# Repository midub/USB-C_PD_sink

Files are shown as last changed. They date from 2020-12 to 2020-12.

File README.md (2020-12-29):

# USB-C Power Delivery sink
A board that negotiates voltage with PD compatible power supply.

				An easy way to bring USB-C power to your own project.

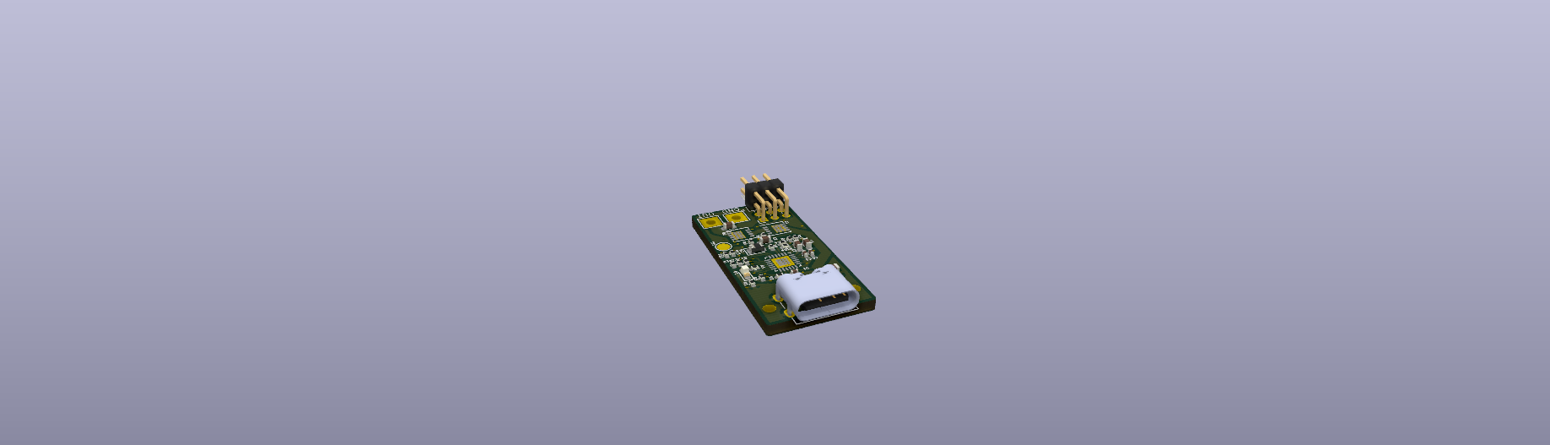
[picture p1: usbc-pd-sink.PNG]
A little board USB-C Power Delivery sink


### Features
- Utilizes Cypress semiconductor's [CYPD3177](https://www.cypress.com/file/460416/download) IC.
- Tiny 32x16 mm board.
- Up to 3A current thanks to quality components.
- Set voltage by specified resistor value or by I2C.
- Access to I2C, GPIO_1, Interupt and Flip pins that are wired out to a 2x3 1.27mm pitch pin header.
- Screw holes next to usb-c port for better attachment.

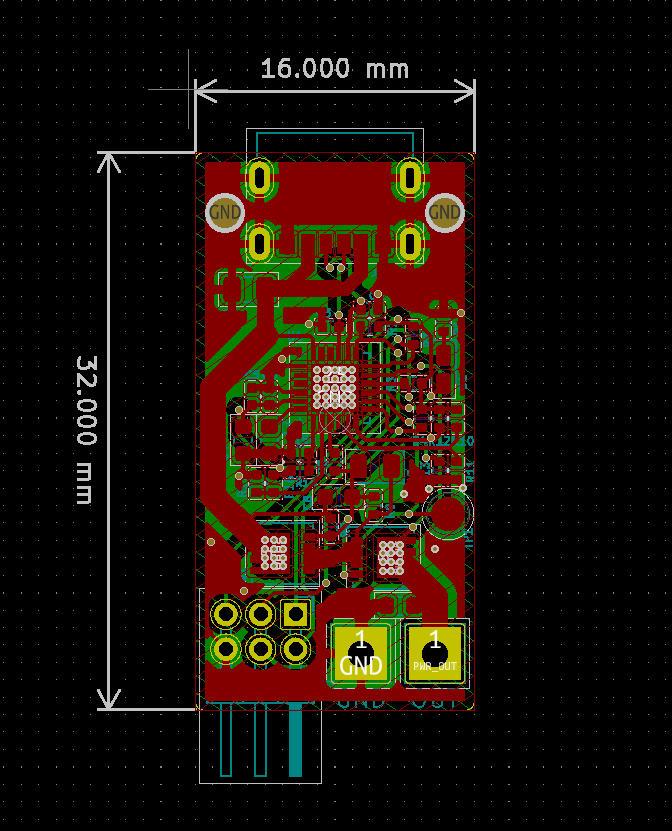
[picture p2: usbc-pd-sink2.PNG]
PCB footprint


### Todos
- Replace output power pins with fastons or othes suitable common connector.
- Create a design block, which can be used by powered board.

## DISCLAIMER: Use at your own risk

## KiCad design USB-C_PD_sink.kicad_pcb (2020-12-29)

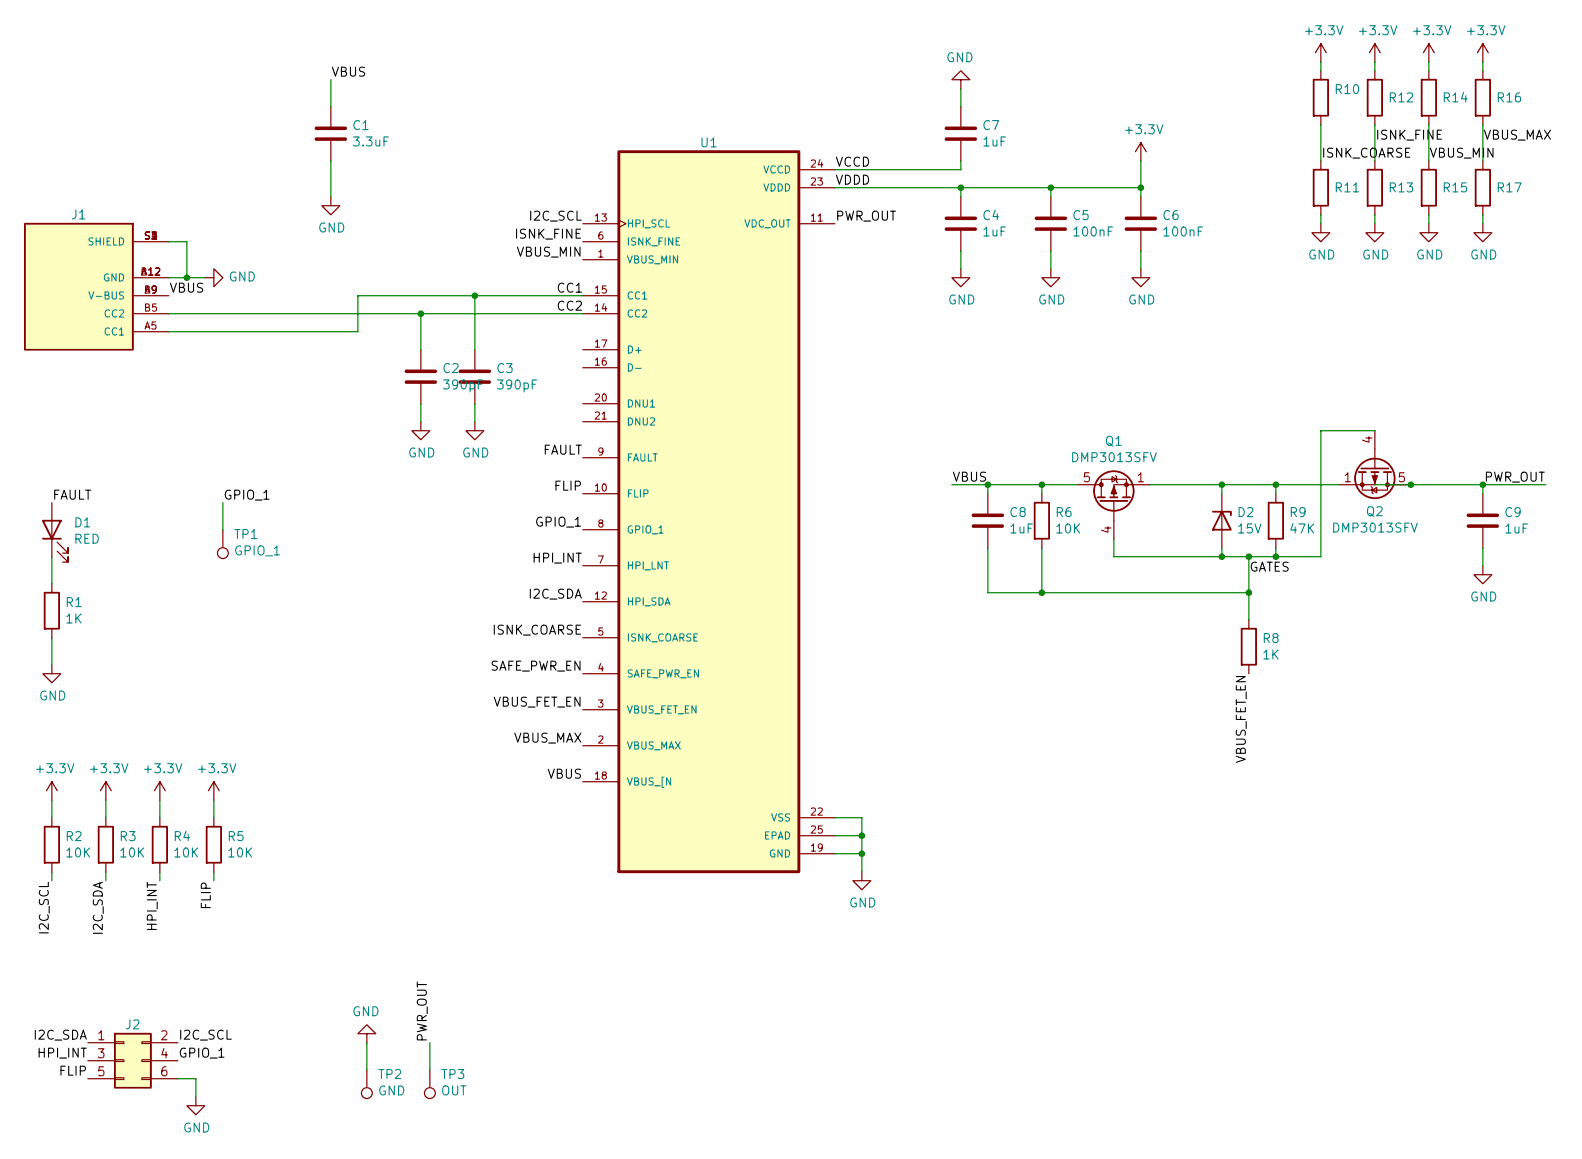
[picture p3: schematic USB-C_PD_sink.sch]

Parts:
C1: 3.3uF; C_0805_2012Metric
C2, C3: 390pF; C_0402_1005Metric
C4, C7, C8, C9: 1uF; C_0603_1608Metric
C5, C6: 100nF; C_0402_1005Metric
D1: RED; LED_0603_1608Metric_Castellated
D2: 15V; D_0805_2012Metric
J1: UJC-HP-3-SMT-TR; CUI_UJC-HP-3-SMT-TR; PARTREV 1.0
J2: Conn_02x03_Odd_Even; PinHeader_2x03_P2.00mm_Horizontal
Q1, Q2: DMP3013SFV; Diodes_PowerDI3333-8
R1, R8: 1K; R_0402_1005Metric
R2, R3, R4, R5, R6: 10K; R_0402_1005Metric
R9: 47K; R_0402_1005Metric
R10, R11, R12, R13, R14, R15, R16, R17: OPT; R_0402_1005Metric
TP1: GPIO_1; TestPoint_Pad_D2.0mm
TP2: GND; TestPoint_THTPad_3.0x3.0mm_Drill1.5mm
TP3: OUT; TestPoint_THTPad_3.0x3.0mm_Drill1.5mm
U1: CYPD3177-24LQXQ; QFN50P400X400X60-25N

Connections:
+3V3: C4.1, C5.1, C6.1, R2.1, R3.1, R4.1, R5.1, R10.1, R12.1, R14.1, R16.1, U1.23 (VDDD)
/CC1: C3.1, J1.A5 (CC1), U1.15 (CC1)
/CC2: C2.1, J1.B5 (CC2), U1.14 (CC2)
/FAULT: D1.2 (A), U1.9 (FAULT)
/FLIP: J2.5, R5.2, U1.10 (FLIP)
/GATES: C8.2, D2.2 (A), Q1.4 (G), Q2.4 (G), R6.2, R8.1, R9.2
/GPIO_1: J2.4, TP1.1, U1.8 (GPIO_1)
/HPI_INT: J2.3, R4.2, U1.7 (HPI_LNT)
/I2C_SCL: J2.2, R2.2, U1.13 (HPI_SCL)
/I2C_SDA: J2.1, R3.2, U1.12 (HPI_SDA)
/ISNK_COARSE: R10.2, R11.1, U1.5 (ISNK_COARSE)
/ISNK_FINE: R12.2, R13.1, U1.6 (ISNK_FINE)
/PWR_OUT: C9.1, Q2.5 (D), TP3.1, U1.11 (VDC_OUT); also elsewhere on the board
/SAFE_PWR_EN: U1.4 (SAFE_PWR_EN)
/VBUS: C1.1, C8.1, J1.A9 (V-BUS), J1.B9 (V-BUS), Q1.5 (D), R6.1, U1.18 (VBUS_[N)
/VBUS_FET_EN: R8.2, U1.3 (VBUS_FET_EN)
/VBUS_MAX: R16.2, R17.1, U1.2 (VBUS_MAX)
/VBUS_MIN: R14.2, R15.1, U1.1 (VBUS_MIN)
/VCCD: C7.2, U1.24 (VCCD)
GND: C1.2, C2.2, C3.2, C4.2, C5.2, C6.2, C7.1, C9.2, J1.A12 (GND), J1.B12 (GND), J1.S1 (SHIELD), J1.S2 (SHIELD), J1.S3 (SHIELD), J1.S4 (SHIELD), J2.6, R1.2, R11.2, R13.2, R15.2, R17.2, TP2.1, U1.19 (GND), U1.22 (VSS), U1.25 (EPAD); also elsewhere on the board
unnamed: D1.1 (K), R1.1
unnamed: D2.1 (K), Q1.1 (S), Q1.2 (S), Q1.3 (S), Q2.1 (S), Q2.2 (S), Q2.3 (S), R9.1

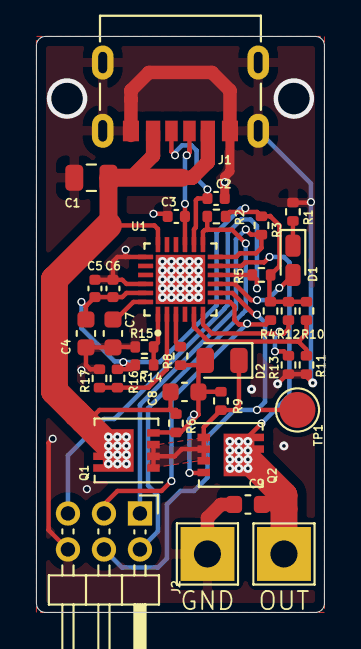
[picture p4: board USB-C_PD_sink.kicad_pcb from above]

Board: 2 copper layers, 16.0 x 32.0 mm, 35 parts (0 on the bottom side), 21 nets.

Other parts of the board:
GND: GND; TestPoint_THTPad_3.0x3.0mm_Drill1.5mm
OUT: OUT; TestPoint_THTPad_3.0x3.0mm_Drill1.5mm

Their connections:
/PWR_OUT: OUT.1; also elsewhere on the board
GND: GND.1; also elsewhere on the board
